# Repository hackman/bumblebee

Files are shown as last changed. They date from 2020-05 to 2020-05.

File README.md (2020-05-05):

The bumblebee project is a controller for automating the control of the lights(daylights, low and high beams) of a car
and also implementing start/stop functionality with a button.

Currently the crank time is hardcoded, it may be possible to be replaced by constant
measurement of the voltage, while the starter motor is cranking, but this has to be
live tested, before I implement that.

This is the code for Arduino, for controlling the lights and starting my car.

When the controller first starts, it is immediately put to sleep. This is to ensure
consistancy between clicks of the start/stop button.

Two different modes of operation:
- If the car is already running
  When the start button is pressed, the controller should:
   - turn off ACC
   - wait for 5min and turn off daylights and lights(low beams)
   - go to sleep
- If the car is not running
  When the start button is pressed, the controller should:
   - if the controller is in sleep mode handle the interrupt and continue
   - check and if ACC is not on and turn it on
   - if the engine is not running and the break pedal is pressed it should turn on the ignition for 7sec
   - if the ignition is not on, turn the daylights on
   - check the photoresistor sensor, if it is determined that it is dark outside, it should turn on the lights(low beams)

Definition for the car is running:
 - the voltage measured from the car is above 13.0V
 - this assumption is based on the fact, that alternator is supposed to charge the battery with 14+ volts

Bill of materials:
- Arduino Uno or Arduino Mini Pro
- Photoresistor
- Button for start/stop
- Button for the break pedal
- 2x 10k Ohm resistor
- 1x 100k Ohm resistor
- One board with 4 relays

Requirements for this project:
 - light measurements
 - voltage measurements
 - detection of break pedal
 - is the shift lever in gear(any gear)

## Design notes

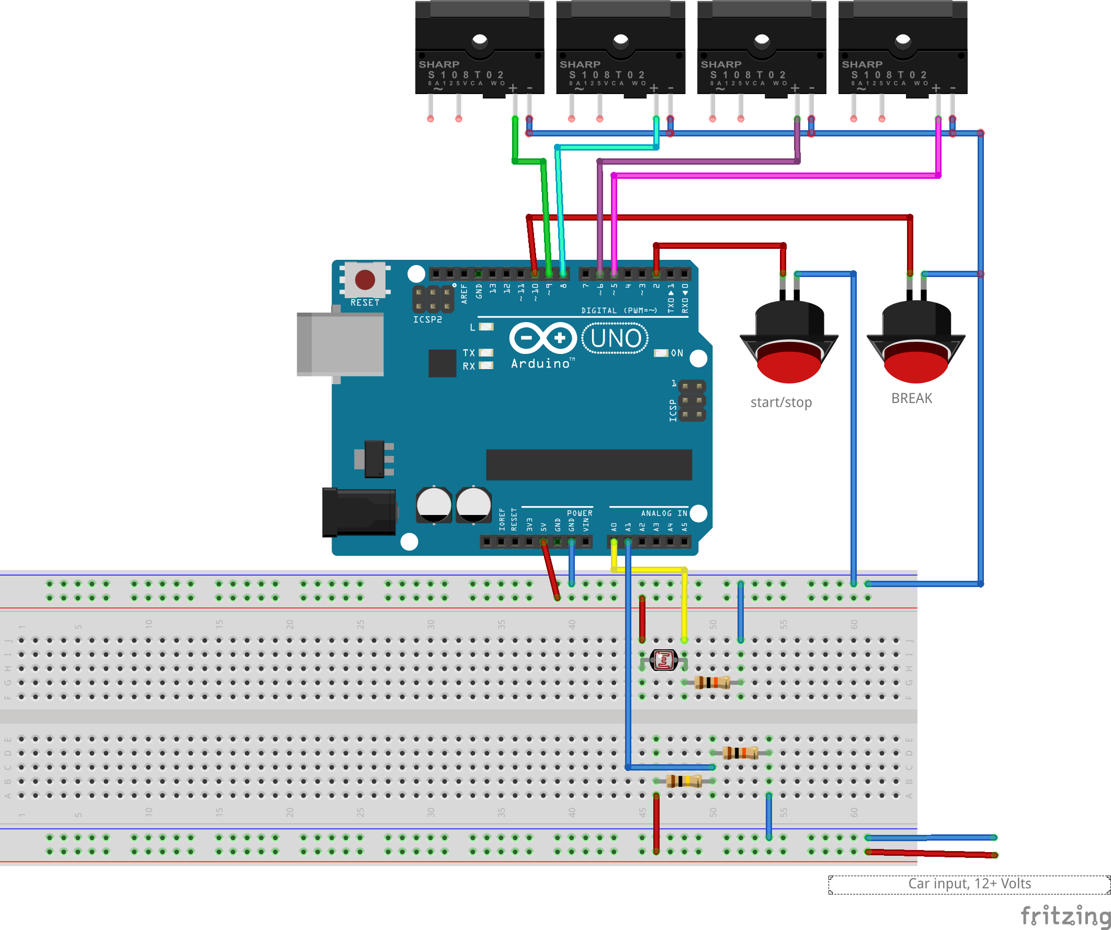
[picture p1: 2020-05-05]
Fritzing/Maznio-lights.png

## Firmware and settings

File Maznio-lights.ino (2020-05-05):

#include <avr/sleep.h>

#define VERSION "0.4"
#define DEBUG
#define INGEAR 11
#define BREAKPEDAL 10
#define DAYLIGHTS 9
#define LIGHTS 8
#define HIGHBEAMS 7
#define ACC 6
#define IGNITION 5
#define START 2
#define INTPIN 2
#define LIGHTSENSOR A0
#define VOLTAGE A1
#define MIN_VOLTAGE 13.0
#define STARTER_TIME 4000
#define LONG_PRESS 1500
#define R1 100000.0 // resistance of R1 (100K) connected to +
#define R2 10000.0  // resistance of R2 (10K) connected to GND on the board and on the voltage source GND
//#define LIGHTS_TURN_OFF_TIME 300000	// 5 minutes
#define LIGHTS_TURN_OFF_TIME 5000
#define DAYLIGHT_VALUE 300

// States
bool daylights = false;
bool lights = false;
bool highbeams = false;
bool acc = false;
bool ignition = false;
bool break_pedal = false;
bool car_started = false;
bool turn_lights_off = false;
bool button_long_active = false;
bool button_active = false;

int  lightsensor = 0;
long button_timer = 0;
long starter_timer = 0;
long stop_lights_timer = 0;

void wakeup() {
	sleep_disable();	// Disable sleep mode
	detachInterrupt(0);	// Detach the interrupt from INTPIN(d2 - INT 0) to prevent a loop of interrupts
#ifdef DEBUG
	Serial.println("Interrupt disabled");
#endif
}

void initController() {
	sleep_enable();
	attachInterrupt(0, wakeup, LOW); 		// attaching an interrupt to INTPIN(d2 - INT 0)
#ifdef DEBUG
	Serial.println("Putting the controller to sleep");
#endif
	set_sleep_mode(SLEEP_MODE_PWR_DOWN);	// Full sleep
	delay(1000);
	sleep_cpu();
#ifdef DEBUG
	Serial.println("Resetting values");
#endif
	// Reset values
	ignition = false;
	acc = false;
	turn_lights_off = false;
	lightsensor = 0;
	button_timer = 0;
	starter_timer = 0;
	stop_lights_timer = 0;
	button_active = false;
	button_long_active = false;
	button_timer = 0;
}

void setup() {
	Serial.begin(38400);
	Serial.println("Starting Maznio ECU1 version " VERSION);
	// Setup inputs
	pinMode(LIGHTSENSOR, INPUT);
	pinMode(INGEAR, INPUT_PULLUP);
	pinMode(BREAKPEDAL, INPUT_PULLUP);
	pinMode(VOLTAGE, INPUT);
	pinMode(INTPIN, INPUT_PULLUP);

	// Setup outputs
	pinMode(DAYLIGHTS, OUTPUT);
	pinMode(LIGHTS, OUTPUT);
	pinMode(HIGHBEAMS, OUTPUT);
	pinMode(ACC, OUTPUT);
	pinMode(IGNITION, OUTPUT);

	initController();
}

bool isCarStarted() {
	int value = 0;
	float result = 0.0;
	value = analogRead(VOLTAGE);

	float voltage = (value * 5.0) / 1023.0; // 5.0V is the voltage of the controller. Here we are converting the analog integer value into the float value of the voltage
	// Because we use a voltage devider, we need to calculate the correct value that we are reading.
	// With R1(100k) and R2(10k) we can measure between 0-55V, so we need to adjust the value to match our reading of 0-5V
	result = voltage / (R2 / (R1 + R2));

	if (result < MIN_VOLTAGE) {
#ifdef DEBUG
		Serial.print("Engine did not start. Voltage: ");
		Serial.println(result);
#endif
		return false;
	} else {
#ifdef DEBUG
		Serial.print("Engine running, voltage: ");
		Serial.println(result);
#endif
		car_started = true;
		return true;
	}
}

bool have_light() {
	lightsensor = analogRead(LIGHTSENSOR);

	if (lightsensor > DAYLIGHT_VALUE){
#ifdef DEBUG
		Serial.print("Daylight detected. Value: ");
		Serial.println(lightsensor);
#endif
		return true;
	} else{
		return false;
	}
}

void lights_on() {
	if (!daylights) {
		digitalWrite(DAYLIGHTS, HIGH);
		daylights = true;
#ifdef DEBUG
		Serial.println("Turrning daylights ON");
#endif
	}
	if (car_started && !lights && !have_light()) {
		digitalWrite(LIGHTS, HIGH);
		lights = true;
#ifdef DEBUG
		Serial.println("Turrning low beams ON");
#endif
	}
}

void check_lights() {
	if (car_started && !have_light() && !lights) {
		digitalWrite(LIGHTS, HIGH);
#ifdef DEBUG
		Serial.println("Turrning low beams ON - checker");
#endif
		lights = true;
	}
}

void lights_off() {
	// Do not try to stop the lights if turn_lights_off is not set by stop_car()
	if (!turn_lights_off)
		return;

	if (millis() - stop_lights_timer > LIGHTS_TURN_OFF_TIME) {
		stop_lights_timer = 0;
		if (lights) {
			digitalWrite(LIGHTS, LOW);
			lights = false;
#ifdef DEBUG
			Serial.println("Turrning lights OFF");
#endif
		}
		if (daylights) {
			digitalWrite(DAYLIGHTS, LOW);
			daylights = false;
#ifdef DEBUG
			Serial.println("Turrning daylights OFF");
#endif
		}
		// Do not put the controller to sleep if the car is still started
		if (!car_started)
			initController();
	}
}

void start_car() {
	// If we try to start the car, during the stop_lights_timer we have to clear the timer
	if (turn_lights_off) {
		stop_lights_timer = 0;
		turn_lights_off = false;
	}
	if (acc) {
#ifdef DEBUG
		Serial.println("ACC already ON");
#endif
	} else {
#ifdef DEBUG
		Serial.println("Turning ACC ON");
#endif
		digitalWrite(ACC, HIGH);
		acc = true;
	}

	// If we are in the ignition phase, don't continue
	if (ignition) {
#ifdef DEBUG
		Serial.println("Ignition motor already ON");
#endif
		return;
	}

	if (car_started) {
#ifdef DEBUG
		Serial.println("Car is already started");
#endif
		return;
	}

	if (digitalRead(BREAKPEDAL) == LOW) {
		if (daylights) {
#ifdef DEBUG
			Serial.println("Turn Daylights OFF");
#endif
			digitalWrite(DAYLIGHTS, LOW);
			daylights = false;
		}

#ifdef DEBUG
    Serial.println("Turning Ignition ON");
#endif
		digitalWrite(IGNITION, HIGH);
		starter_timer = millis();
		ignition = true;
	}
}

void stop_starter() {
	// If the starter motor is not working at the moment, we have nothing to do here
	if (!ignition)
		return;

	// Check if more then STARTER_TIME has passed since the started motor been turned on
	if (millis() - starter_timer > STARTER_TIME) {
		digitalWrite(IGNITION, LOW);
		starter_timer = 0;
		ignition = false;
#ifdef DEBUG
		Serial.println("Turning ignition OFF");
#endif
		if (isCarStarted()) {
			lights_on();
		}
	}
}

void stop_car() {
	if (acc) {
		digitalWrite(ACC, LOW);
		acc = false;
#ifdef DEBUG
		Serial.println("Engine turn OFF");
#endif
	} else {
#ifdef DEBUG
		Serial.println("Engine already OFF");
#endif
	}

	car_started = false;
	turn_lights_off = true;
	delay(1500);
	stop_lights_timer = millis();
}

void check_button() {
	if (digitalRead(START) == LOW) {
		if (button_active == false) {
			button_active = true;
			button_timer = millis();
		}
		if ((millis() - button_timer > LONG_PRESS) && (button_long_active == false)) {
#ifdef DEBUG
			Serial.println("Long press detected");
#endif
			button_long_active = true;
			stop_car();
		}
	} else {
		if (button_active == true) {
			if (button_long_active == true) {
				button_long_active = false;
			} else {
				start_car();
			}
			button_active = false;
		}
	}
}

void loop() {
	check_button();
	stop_starter();
	check_lights();
	lights_off();
}

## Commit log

2020-05-04 TODO file - Currently includes only high/low beams detection
2020-05-05 Maznio-lights.ino: This is the first beta version of the code - Added voltage monitoring - STARTER_TIME replaced the hardcoder(wrong) number 7, which is 7miliseconds and not 7 seconds - Added lights 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
    [Maznio-lights.ino]
2020-05-05 Maznio-lights.ino: Remove code that prevented the controller to go to sleep if the car haven't started
    [Maznio-lights.ino]
2020-05-05 Added a Fritzing diagram of the wiring
    [Maznio-lights.fzz]
